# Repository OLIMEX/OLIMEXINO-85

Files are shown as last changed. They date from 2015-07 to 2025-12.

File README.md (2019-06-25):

This is the official repository for a number of OLIMEXINO-85 boards, manufactured by Olimex.

OLIMEXINO-85 boards are very tiny Arduino-like boards. They have functionality similar to Digistump's Digispark and Adafruit’s Trinket. The ATtiny85 microcontroller of each board comes preprogrammed with "Micronucleus" bootloater. This bootloader allows you to upload new software to the board via a personal computer and a USB cable. The boards work with the same Arduino distribution as Digispark.

In this repository you would find files suitable for the following boards:  

* OLIMEXINO-85-ASM: https://www.olimex.com/Products/Duino/AVR/OLIMEXINO-85-ASM/open-source-hardware
* OLIMEXINO-85-KIT: https://www.olimex.com/Products/Soldering-Kits/OLIMEXINO-85-KIT/open-source-hardware
* OLIMEXINO-85BC: https://www.olimex.com/Products/Duino/AVR/OLIMEXINO-85BC/open-source-hardware
* OLIMEXINO-85S: https://www.olimex.com/Products/Duino/AVR/OLIMEXINO-85S/open-source-hardware
* FOSDEM-85: https://www.olimex.com/Products/Soldering-Kits/FOSDEM-85/open-source-hardware

The SIMON-85 and SIMON-85-KIT boards have own repository available here: https://github.com/OLIMEX/SIMON-85

This repository contains a number of software files - firmware binaries, Arduino libraries, and ready-to-use examples. Note that the software files for the mentioned boards are the same for all boards in this repository. However, the hardware source files and pdfs for the above-mentioned boards are not the same.

##LICENSE
* Software License is GPL3
* Hardware License is Apache 2.0
* Documentation License is CC-BY-SA3.0 (https://creativecommons.org/licenses/by-sa/3.0/)

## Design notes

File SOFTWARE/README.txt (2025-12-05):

There are three sub-folders:

1. O85-examples
2. Libraries
3. Firmware

To be able to use the demos:

0. You need an Arduino IDE configured for DIGISPARK. You can configure Arduino IDE for ATtiny85 (OLIMEXINO-85-ASM, OLIMEXINO-85-KIT, FOSDEM-85, SIMON-85, SIMON-85-KIT, OLIMEXINO-85BC, OLIMEXINO-85S) following the advice here:

https://web.archive.org/web/20180831071913/http://digistump.com/wiki/digispark/tutorials/connecting

1. Copy the contents of the first folder of this archive "O85_examples" to xxx\arduino-x.x.x\examples\ folder.

2. Copy the contents of folder "libaries" to xxx\arduino-x.x.x\libraries. It is extremely important to paste only the contents there (do not create new folders in it else libraries would not be found).

3. You can now load the examples via Open->Examples or Open -> File in the Arduino IDE

Note that each example has a readme file in its folder detailing furhter how to use it and how it works.

Folder "Firmware" contains the bootloader that can be used to flash the board via any compatible AVR programmer in case of electrical failure or bootloader override.

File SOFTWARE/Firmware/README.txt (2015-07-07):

The firmware binaries are suitable for the following boards that feature ATtiny85: OLIMEXINO-85-KIT, OLIMEXINO-85-ASM, OLIMEXINO-85BC, OLIMEXINO-85S, FOSDEM-85, and FOSDEM-85-KIT

The OLIMEXINO-85 boards come programmed with the "Micronucleus" bootloader version 1.06. The offical "Micronucleus" repository can be found at the following address: https://github.com/micronucleus/micronucleus 

We used the Bluebie fork available here: https://github.com/Bluebie/micronucleus/tree/master/firmware/releases

NOTE: We are not supporting upgrading the firmware - the only suggested firmware is the bootloader version 1.06. It is provided in the respective folder.

1) Use AVR/Atmel Studio or AVRDude to upload respectivley the .elf or the .hex to the target ATtiny85.

The .elf file contains the proper fuses and configuration bits.

2) If you use AVRDude then you need to pass the fuse settings as command line:

lfuse:w:0xE1:m -U hfuse:w:0xDD:m -U efuse:w:0xFE:m

Usually the command to program the board via AVRDude looks like:

avrdude -c stk500v2 -P com26 -p t85 -U flash:w:Olimexino-85_ProductionTest_v_1_0_0.hex -U lfuse:w:0xE1:m -U hfuse:w:0xDD:m -U efuse:w:0xFE:m

,where

stk500v2 is the programmer's interface abriviation as per AVRdude's documentation
com26 is the serial interface in Windows; it would be something like ttyACM0 or similar
t85 is the abriviation of the name of the target microcontroller as per AVRdude's documentation
Olimexino-85_ProductionTest_v_2_0_0.hex is the name of our binary code

3) About the ATTINY85 Fuses
========================
FUSE - HEX value - Value description

Extended fuse - 0xFE – this value enables self programming and keeps the serial programming enabled

High fuse - 0xDD – this values sets PLL Clock; start-up time PWRDWN/RESET: 1K CK/14 CK + 64 ms

Low fuse - 0xE1 – this values sets brown-out detection at VCC=2.7 V

Refer to the user's manual of OLIMEXINO-85 for more information.

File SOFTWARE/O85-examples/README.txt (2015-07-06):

OLIMEXINO-85-ASM, OLIMEXINO-85-KIT, OLIMEXINO-85BC, OLIMEXINO-85S and FOSDEM-85 example package

1. Hardware and software prerequisites:

1x OLIMEXINO-85 board
1x cable to connect the board and your PC
1x properly installed Digispark Arduino IDE (please note that the examples won't work with stock Arduino IDE!)

Each example is archived as zip. Please extract it to a suitable folder to be able to load it in Arduino IDE. To prepare the Arduino IDE follow the guide available here:

http://digistump.com/wiki/digispark/tutorials/connecting

Some examples require additional hardware! Each example has explanation in the code comments!

2. The example list consists of:

85_ADCtoPWM.zip
85_BB_A4983.zip
85_BB_VNH3SP30.zip
85_BlinkingLed.zip
85_Button.zip
85_MOD_TC_MK2.zip
85_PWM.zip
85_Thermometer.zip

3. Remember:

- you need an Arduino IDE configured for DIGISPARK

- you need to click "Upload" button first, wait for the program to compile and THEN plug the board (this is because the bootloader implementation runs for the first few seconds after power up and then the user program is executed. If you plug the board before programming the bootloader won't be available and uploading will fail. Disconnect the board, click "Upload" again and then connect the board).

There are detailed instructions in the manual and the digispark's wiki pages.

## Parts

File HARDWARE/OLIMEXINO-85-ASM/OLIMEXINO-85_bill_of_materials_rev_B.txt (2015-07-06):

Partlist exported from D:/TortoiseSVN-Files/EagleProjects-LocalCopies/OLIMEXINO-85/Hardware/trunk/BRD/Olimexino-85_Rev_A.sch at 25/10/2013 8:02:23 

Qty Value                         Device          Parts                             
3   1.5k/0.125W                   R-EU_0204/5     R1, R2, R3                        
2   1N4148/DO35                   D1N4148-7.62MM  D1, D2                            
1   10uF/16V/105C(5x11mm,RM2)     CPOL-EUE2-5     C1                                
2   22R/0.125W                    R-EU_0204/5     R4, R5                            
1   100nF/2010                    C-EU025-025X050 C2                                
1   ATtiny85-20PU+(DIL-8)+(HR1x8) ATTINY85        U1                                
1   LED/3mm/Green                 LED3.0MM        PWR                               
1   LED/3mm/Red                   LED3.0MM        STAT                                                        
8   TESTPAD3                      TESTPAD3        #0, #1, #2, #3, #4, #RST, GND, VCC
1   TSR-1(T1101GP/6x3x4.3)        SW-TAKT3        RST                               
1   USB-B                         USB_SHIELD      USB

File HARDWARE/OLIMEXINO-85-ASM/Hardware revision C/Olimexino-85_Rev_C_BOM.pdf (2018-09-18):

Olimexino-85_Rev_C

Part | Value | Device | Package | Description
#0 | TESTPAD3 | TESTPAD3 | TEST_PAD40/70/SQUARE drill 40mils, diameter 70mils

#1 | TESTPAD3 | TESTPAD3 | TEST_PAD40/70/SQUARE drill 40mils, diameter 70mils

#2 | TESTPAD3 | TESTPAD3 | TEST_PAD40/70/SQUARE drill 40mils, diameter 70mils

#3 | TESTPAD3 | TESTPAD3 | TEST_PAD40/70/SQUARE drill 40mils, diameter 70mils

#4 | TESTPAD3 | TESTPAD3 | TEST_PAD40/70/SQUARE drill 40mils, diameter 70mils

#RST | TESTPAD3 | TESTPAD3 | TEST_PAD40/70/SQUARE drill 40mils, diameter 70mils

C1 | 10uF/16V/105C(5x11mm,RM2) | CPOL-EUE2-5 | E2-5 | POLARIZED CAPACITOR, European symbol
C2 | 100nF/2010 | C-EU025-025X050 | C025-025X050 | CAPACITOR, European symbol
D1 | 1N4148/DO35 | D1N4148-7.62MM | DO35-10 | DIODES
D2 | 1N4148/DO35 | D1N4148-7.62MM | DO35-10 | DIODES
GND | TESTPAD3 | TESTPAD3 | TEST_PAD40/70/SQUARE drill 40mils, diameter 70mils
PWR | LED/3mm/Green | LED3.0MM | LED-3.0MM
R1 | 1.5k/0.125W | R-EU_0204/5 | 0204/5 | RESISTOR, European symbol
R2 | 1.5k/0.125W | R-EU_0204/5 | 0204/5 | RESISTOR, European symbol
R3 | 1.5k/0.125W | R-EU_0204/5 | 0204/5 | RESISTOR, European symbol
R4 | 22R/0.125W | R-EU_0204/5 | 0204/5 | RESISTOR, European symbol
R5 | 22R/0.125W | R-EU_0204/5 | 0204/5 | RESISTOR, European symbol
R6 | NA | R-EU_R0603_5MIL_DWS R0603_5MIL_DWS | RESISTOR, European symbol
R7 | NA | R-EU_R0603_5MIL_DWS R0603_5MIL_DWS | RESISTOR, European symbol
R8 | NA | R-EU_R0603_5MIL_DWS R0603_5MIL_DWS | RESISTOR, European symbol
RST | TSR-1(T1101GP/6x3x4.3) | SW-TAKT3 | SW-TAKT6X3.5
RST_E Open | SJSJ_SMALLER | SJ_1_SMALLER | SMD solder JUMPER
STAT | LED/3mm/Red | LED3.0MM | LED-3.0MM
U1 | ATtiny85-20PU+(DIL-8)+(HR1x8) ATTINY85 | DIP8
USB | USB-B | USB_SHIELD | USB_NEAR_BLACK
VCC | TESTPAD3 | TESTPAD3 | TEST_PAD40/70/SQUARE drill 40mils, diameter 70mils
Z1 | NA(BZV55C3V6/SOD80C) | ZDIOD-SMD | MINI-MELF
Z2 | NA(BZV55C3V6/SOD80C) | ZDIOD-SMD | MINI-MELF

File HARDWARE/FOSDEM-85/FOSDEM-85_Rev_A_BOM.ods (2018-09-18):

Part | Value | Device | Package | Description
#0 | TESTPAD3 | TESTPAD3 | TEST_PAD40/70/SQUARE | drill 40mils, diameter 70mils
#1 | TESTPAD3 | TESTPAD3 | TEST_PAD40/70/SQUARE | drill 40mils, diameter 70mils
#2 | TESTPAD3 | TESTPAD3 | TEST_PAD40/70/SQUARE | drill 40mils, diameter 70mils
#3 | TESTPAD3 | TESTPAD3 | TEST_PAD40/70/SQUARE | drill 40mils, diameter 70mils
#4 | TESTPAD3 | TESTPAD3 | TEST_PAD40/70/SQUARE | drill 40mils, diameter 70mils
#RST | TESTPAD3 | TESTPAD3 | TEST_PAD40/70/SQUARE | drill 40mils, diameter 70mils
BAT-3.7V | DW02S | CON2DW02S | DW02S
C1 | 10uF/16V/105C(5x11mm,RM2) | CPOL-EUE2-5 | E2-5 | POLARIZED CAPACITOR, European symbol
C2 | 100nF/2010 | C-EU025-025X050 | C025-025X050 | CAPACITOR, European symbol
D1 | 1N4148/DO35 | DDO35 | DO35-200MILS | DIODES
D2 | 1N4148/DO35 | DDO35 | DO35-200MILS | DIODES
D3 | 1N4148/DO35 | DDO35 | DO35-200MILS | DIODES
GND | TESTPAD3 | TESTPAD3 | TEST_PAD40/70/SQUARE | drill 40mils, diameter 70mils
PWR | LED/3mm/Green | LED3.0MM | LED-3.0MM
R1 | 10k/0.125W | R-EU_0204/5 | 0204/5 | RESISTOR, European symbol
R2 | 1.5k/0.125W | R-EU_0204/5 | 0204/5 | RESISTOR, European symbol
R3 | 1.5k/0.125W | R-EU_0204/5 | 0204/5 | RESISTOR, European symbol
R4 | 22R/0.125W | R-EU_0204/5 | 0204/5 | RESISTOR, European symbol
R5 | 22R/0.125W | R-EU_0204/5 | 0204/5 | RESISTOR, European symbol
R6 | 10k/0.125W | R-EU_0204/5 | 0204/5 | RESISTOR, European symbol
STAT | LED/3mm/Red | LED3.0MM | LED-3.0MM
U1 | ATtiny85-20PU+(DIL-8) | ATTINY85-20PU | DIP8 | Atmel 8-bit AVR 2/4/8KB In-System Programmable Flash
USB | USB-B | USB_SHIELD | USB_NEAR_BLACK
VCC | TESTPAD3 | TESTPAD3 | TEST_PAD40/70/SQUARE | drill 40mils, diameter 70mils

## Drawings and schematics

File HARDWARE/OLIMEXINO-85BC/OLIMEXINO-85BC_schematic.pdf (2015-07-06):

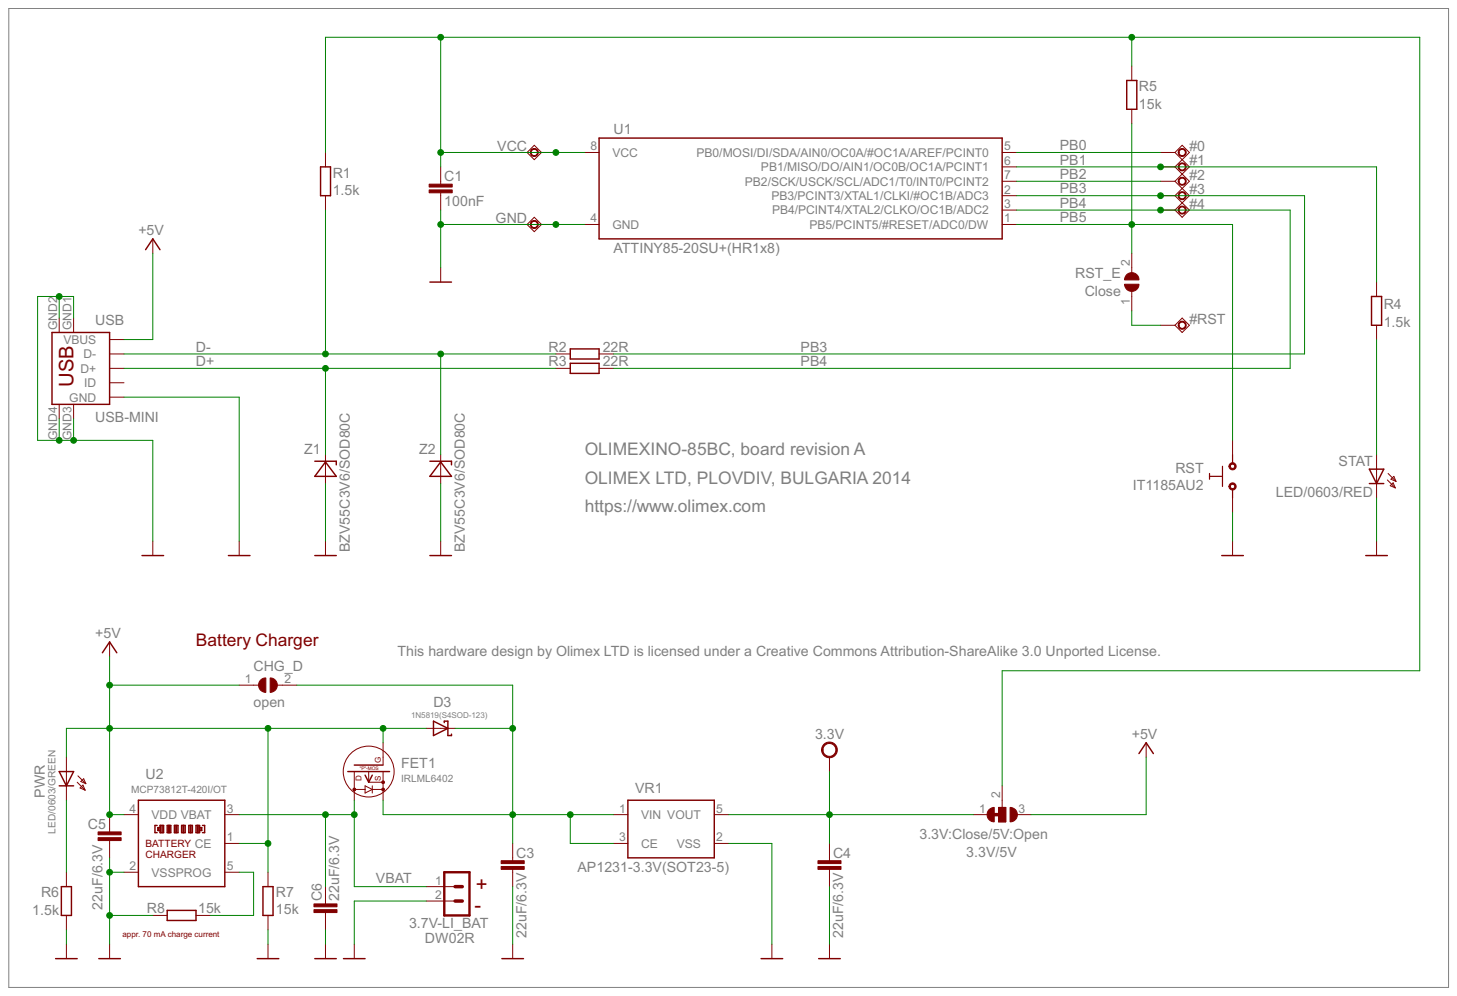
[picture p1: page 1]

6 PB0/MOSI/DI/SDA/AIN0/OC0A/#OC1A/AREF/PCINT0

PB4 | #4
PB5

OLIMEXINO-85BC, board revision A
OLIMEX LTD, PLOVDIV, BULGARIA 2014
https://www.olimex.com

This hardware design by Olimex LTD is licensed under a Creative Commons Attribution-ShareAlike 3.0 Unported License.

appr. 70 mA charge current

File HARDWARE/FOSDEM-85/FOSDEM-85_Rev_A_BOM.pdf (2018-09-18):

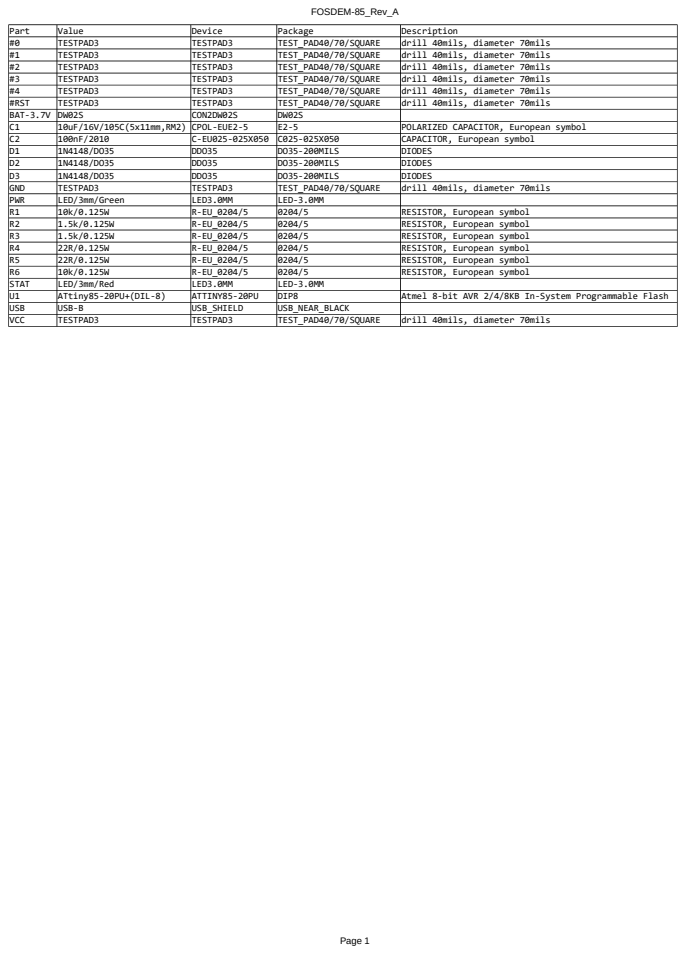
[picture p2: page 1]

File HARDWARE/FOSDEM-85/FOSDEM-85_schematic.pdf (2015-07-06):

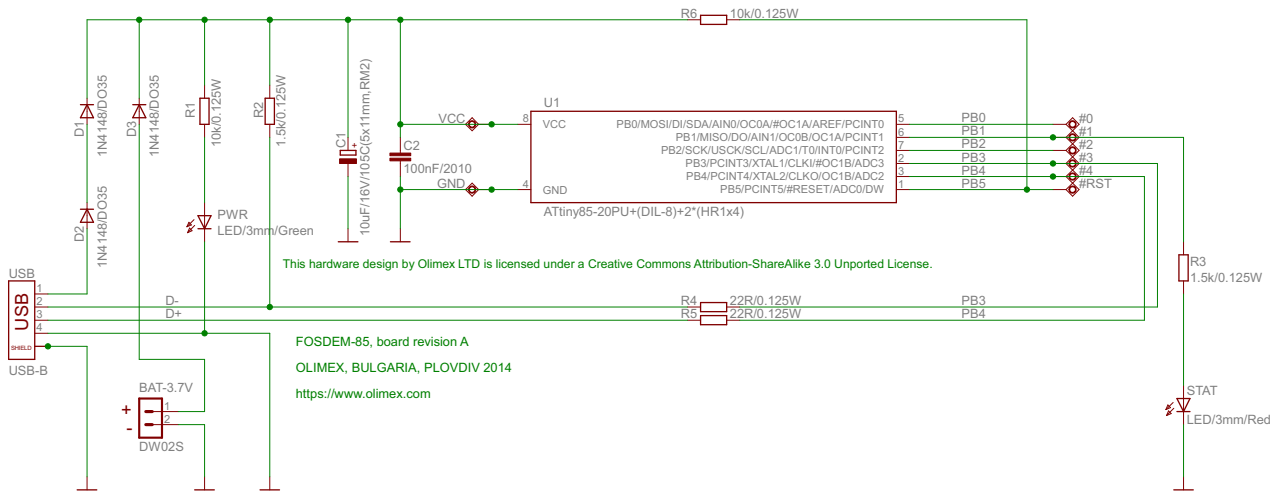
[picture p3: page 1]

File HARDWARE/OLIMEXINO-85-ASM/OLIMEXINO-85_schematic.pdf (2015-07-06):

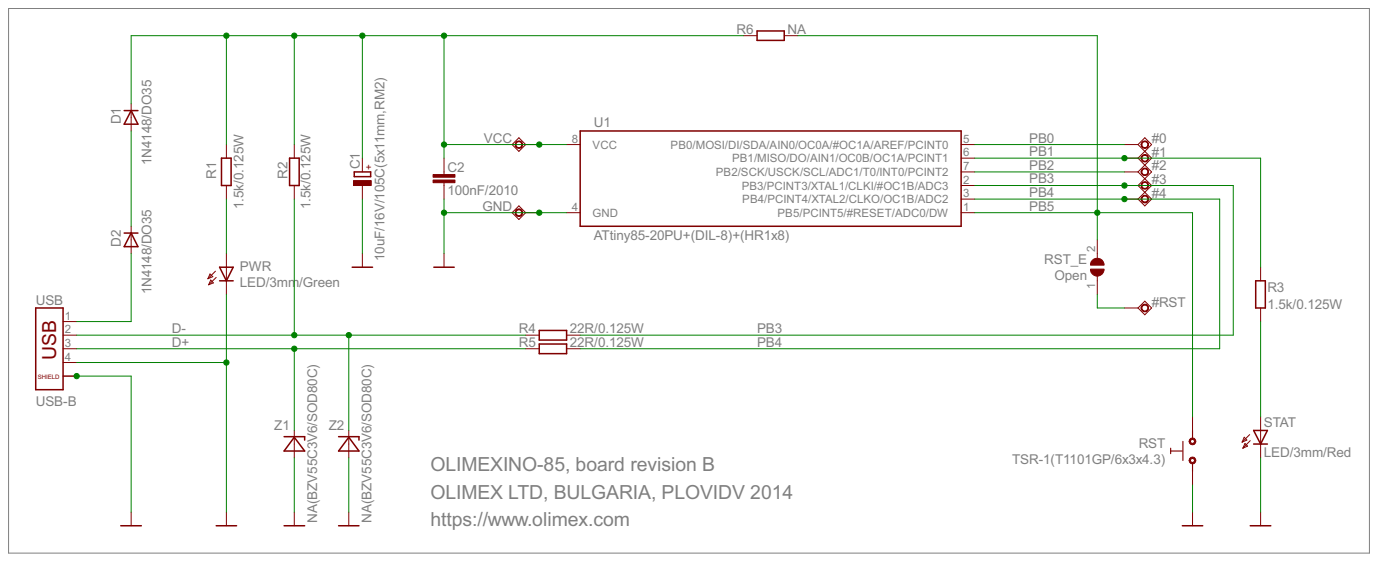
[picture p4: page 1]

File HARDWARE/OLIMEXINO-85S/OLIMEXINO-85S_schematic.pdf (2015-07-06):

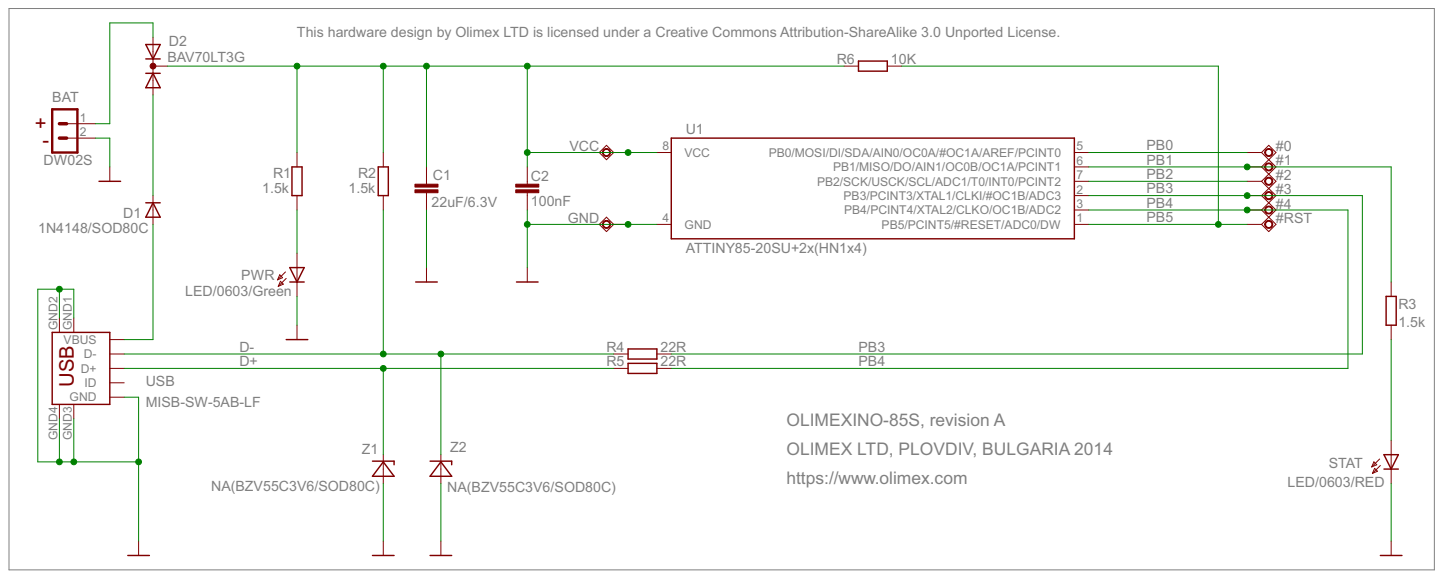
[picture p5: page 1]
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

6 PB0/MOSI/DI/SDA/AIN0/OC0A/#OC1A/AREF/PCINT0

OLIMEXINO-85S, revision A
OLIMEX LTD, PLOVDIV, BULGARIA 2014
https://www.olimex.com

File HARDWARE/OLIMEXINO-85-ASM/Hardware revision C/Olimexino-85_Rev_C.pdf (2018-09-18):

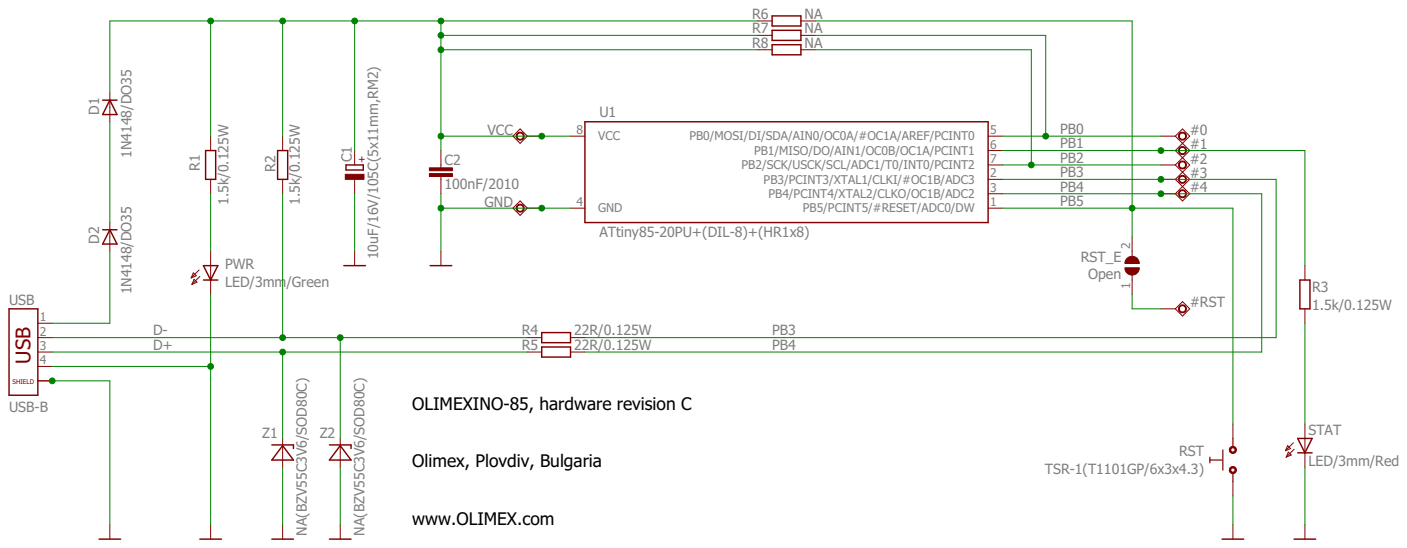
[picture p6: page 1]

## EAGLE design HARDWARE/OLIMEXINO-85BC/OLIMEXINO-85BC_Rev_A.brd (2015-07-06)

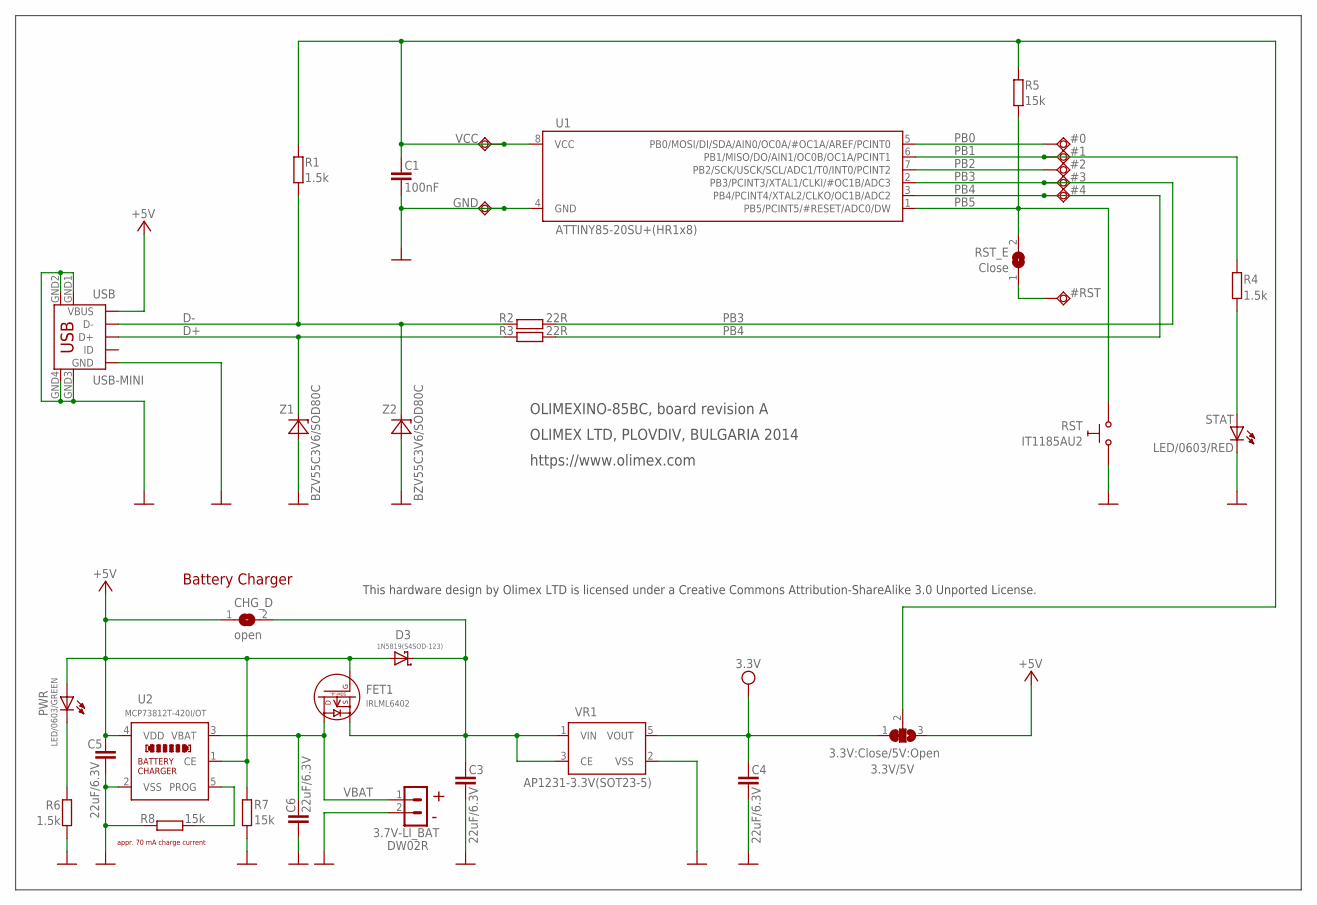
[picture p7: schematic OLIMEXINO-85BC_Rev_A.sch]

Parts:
3.3V/5V: 3.3V:Close/5V:Open; SJ_2_SMALL
3.7V-LI_BAT: DW02R
#0, #1, #2, #3, #4: TESTPAD3; TEST_PAD40/70/SQUARE
#RST: TESTPAD3; TEST_PAD40/70/SQUARE
C1: 100nF; C0603_DWS
C3, C4, C5, C6: 22uF/6.3V; C0603_DWS
CHG_D: open; SJ_1_SMALLER
D3: 1N5819(S4SOD-123); SOD-123
FET1: IRLML6402; SOT23
GND: TESTPAD3; TEST_PAD40/70/SQUARE
PWR: LED/0603/GREEN; LED-0603
R1, R4, R6: 1.5k; R0603_5MIL_DWS
R2, R3: 22R; R0603_5MIL_DWS
R5, R7, R8: 15k; R0603_5MIL_DWS
RST: IT1185AU2
RST_E: Close; SJ_1_SMALLER
STAT: LED/0603/RED; LED-0603
U1: ATTINY85-20SU+(HR1x8); SO-8
U2: MCP73812T-420I/OT; SOT-23-5
USB: USB-MINI; USB_MINI_9PIN
VCC: TESTPAD3; TEST_PAD40/70/SQUARE
VR1: AP1231-3.3V(SOT23-5); SOT-23-5
Z1, Z2: BZV55C3V6/SOD80C; MINI-MELF

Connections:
+5V: 3.3V/5V.3, C5.1, CHG_D.1, D3.A, FET1.1 (G), PWR.A, R7.1, U2.1 (CE), U2.4 (VDD), USB.VBUS
D+: R3.1, USB.D+, Z1.1 (C)
D-: R1.1, R2.1, USB.D-, Z2.1 (C)
GND: 3.7V-LI_BAT.2, C1.2, C3.2, C4.2, C5.2, C6.2, GND.P$1, R6.2, R7.2, R8.1, RST.2 (1), STAT.C, U1.4 (GND), U2.2 (VSS), USB.GND, USB.GND1, USB.GND2, USB.GND3, USB.GND4, VR1.2 (VSS), Z1.2 (A), Z2.2 (A)
MCU_VCC: 3.3V/5V.2, C1.1, R1.2, R5.2, U1.8 (VCC), VCC.P$1
unnamed: #RST.P$1, RST_E.1
unnamed: R4.1, STAT.A
unnamed: PWR.C, R6.1
unnamed: R8.2, U2.5 (PROG)
PB0: #0.P$1, U1.5 (PB0/MOSI/DI/SDA/AIN0/OC0A/#OC1A/AREF/PC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)
PB1: #1.P$1, R4.2, U1.6 (PB1/MISO/DO/AIN1/OC0B/OC1A/PCINT1)
PB2: #2.P$1, U1.7 (PB2/SCK/USCK/SCL/ADC1/T0/INT0/PCINT2)
PB3: #3.P$1, R2.2, U1.2 (PB3/PCINT3/XTAL1/CLKI/#OC1B/ADC3)
PB4: #4.P$1, R3.2, U1.3 (PB4/PCINT4/XTAL2/CLKO/OC1B/ADC2)
PB5: R5.1, RST.1 (0), RST_E.2, U1.1 (PB5/PCINT5/#RESET/ADC0/DW)
VBAT: 3.7V-LI_BAT.1, C6.1, FET1.3 (D), U2.3 (VBAT)
VCC: 3.3V/5V.1, C4.1, VR1.5 (VOUT)
VIN: C3.1, CHG_D.2, D3.C, FET1.2 (S), VR1.1 (VIN), VR1.3 (CE)

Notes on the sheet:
Battery Charger
appr. 70 mA charge current
OLIMEXINO-85BC, board revision A
OLIMEX LTD, PLOVDIV, BULGARIA 2014
https://www.olimex.com
This hardware design by Olimex LTD is licensed under a Creative Commons Attribution-ShareAlike 3.0 Unported License.

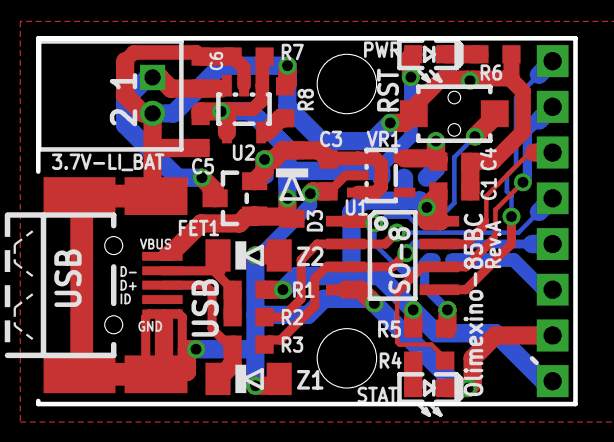
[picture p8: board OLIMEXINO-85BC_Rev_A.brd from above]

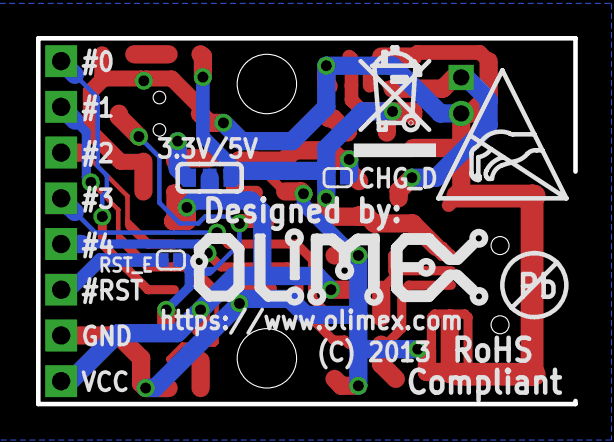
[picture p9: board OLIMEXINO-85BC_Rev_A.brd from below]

Board: 2 copper layers, 29.8 x 20.3 mm, 40 parts (7 on the bottom side), 18 nets.

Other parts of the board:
U$1: RECYCLE_BIN1/8
U$2: OLIMEX1_V
U$3: ESD_SYMBOL
U$4: PB_SMALL

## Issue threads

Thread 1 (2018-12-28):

Installing olimex package library in Arduino

rvegele, 2018-12-28:
The following link seems to be dead:
https://raw.githubusercontent.com/OLIMEX/Arduino_configurations/master/AVR/package_olimex _avr_index.json

Getting an error in arduino ide

newtob, 2021-08-04:
I concur, any ideas where it might be re-listed?

hehopmajieh, 2021-08-04:
Link is ok, try with :
https://raw.githubusercontent.com/OLIMEX/Arduino_configurations/master/AVR/package_olimex_avr_index.json

На ср, 4.08.2021 г. в 10:38 ч. Ben ***@***.***> написа:

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

newtob, 2021-08-04:
You'r a superstar, it works!!

Many thanks,
B
_______
Ben

On Wed, 4 Aug 2021 at 09:21, Dimitar Gamishev ***@***.***>
wrote:

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

Closed 2021-08-17.

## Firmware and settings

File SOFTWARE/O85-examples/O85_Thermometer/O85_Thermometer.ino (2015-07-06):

/**********************************************************************************/
/*    Demo Program for:          						  */
/*	  Board: Olimexino-85                 					  */
/*    Manufacture: OLIMEX                                                   	  */
/*	  COPYRIGHT (C) 2014							  */
/*    Designed by:  Penko T. Bozhkov                                              */
/*    Revision       :  1.0.0 (initial)                                           */
/*    Date           :  31.01.2014                                                */
/*   Built with Arduino C/C++ Compiler, version: 1.0.4                            */
/**********************************************************************************/
// Very important!!!!! Change the I2C buffer size from 16 to 30!!!!!!!!!!!!!!!!!!!!
// Goto Digispark-Arduino-1.0.4\libraries\TinyWireM_Digispark\TinyWire.h and chage:
// #define USI_BUF_SIZE    30              // bytes in message buffer
// In other case, the demo will not work correctly
/*
  Action:
  =======
  Reads the temperature via MOD-TC-MK2-31855 and displays the value to MOD-LCD-1x9.
  https://www.olimex.com/Products/Modules/Sensors/MOD-TC-MK2-31855/open-source-hardware
  https://www.olimex.com/Products/Components/Misc/TC-K-TYPE/
  https://www.olimex.com/Products/Modules/LCD/MOD-LCD-1x9/open-source-hardware
  To connect all boards together we have used one UEXTx5 board as well: 
  https://www.olimex.com/Products/Modules/Interface/UEXTx5/open-source-hardware
  
  Notes: 
    1. Beware VCC not to exceed (3.6~3.8)V!!!!!
    2. Ensure MOD-TC-MK2-31855 I2C pull-ups are not disconnected!
 
  Simple Schematic:
  =================                                                          |----------------------|
  |---------------------------|       |--------------------------|           |   MOD-TC-MK2-31855   |
  |                    |  #0  |-------| UEXT1<6>        UEXT3<6> |-----------| UEXT<6>            T+|------\  +
  |                    |  #1  |       |                 UEXT3<5> |-----------| UEXT<5>              |       o Thermocouple(TC-K-TYPE)
  |                    |  #2  |-------| UEXT1<5>        UEXT3<2> |-----------| UEXT<2>            T-|------/  -
  |    OLIMEXINO-85    |  #3  |       |            U    UEXT3<1> |-----------| UEXT<1>              |
  |                    |  #4  |       |            E             |           |----------------------|
  |                    | #RST |       |            X             |                                
  |                    | GND  |-------| UEXT1<2>   T             |           |------------------| D |
  |                    | VCC  |-------| UEXT1<1>   x    UEXT5<6> |-----------| UEXT<6>          | I |
  |---------------------------|       |            5    UEXT5<5> |-----------| UEXT<5>          | S |
                                      |                 UEXT5<2> |-----------| UEXT<2>          | P |
                                      |                 UEXT5<1> |-----------| UEXT<1>          | L |
                                      |--------------------------|           |    MOD-LCD-1x9   | A |
                                                                             |------------------| Y |

  To upload to your Olimexino-85:
  1) Select the proper board from the Tools->Board Menu->Digispark 8mhz - NO USB(Tiny Core)
  2) Select Digispark from the Tools->Programmer
  3) Press the Upload button
  4) When you see the message: "Plug in device now... (will timeout in 60 seconds)", Plug in the Olimexino-85
*/
#include <USI_TWI_Master.h>
#include <TinyWireM.h>      // By default: SCL -> PB2(#2), SDA -> PB0(#0)
//#include <avr/pgmspace.h>
#include <LCD1x9.h>
#include <inttypes.h>

#define MOD_TC_MK2_ADDR   0x23 
#define GET_TEMP	  0x21

#define LED1_PIN         1              // ATtiny85 Pin 6, PB1(#1)
#define LED2_PIN         4              // ATtiny85 Pin 3, PB4(#4)

char TempValue[9] = {'T','e','m','p',' ',' ',' ','&','C'};
uint16_t count = 1;
uint16_t tempC = 0;                     // holds temp in C
//uint16_t tempF = 0;                     // holds temp in F


/****************************************************/
/*  Function name: TC_MK2_temperatureRead           */
/*  Parameters                                      */
/*    Input   :  No                                 */
/*    Output  :  temp                               */
/*    Action: Returns the MAX31855KASA+'s temp data.*/
/****************************************************/
uint32_t TC_MK2_temperatureRead(){
  uint32_t temp;
  uint8_t data[4];
  uint8_t i = 0;
  
  TinyWireM.beginTransmission(MOD_TC_MK2_ADDR);
  TinyWireM.send(GET_TEMP);
  TinyWireM.endTransmission();
  TinyWireM.requestFrom(MOD_TC_MK2_ADDR,4);
  
  while(TinyWireM.available() > 0)
    data[i++] = TinyWireM.receive();
  
  temp = data[3];
  temp <<= 8;
  temp |= data[2];
  temp <<= 8;
  temp |= data[1];
  temp <<= 8;
  temp |= data[0];
  
  return temp;
}


/****************************************************/
/*  Function name: Blink                            */
/*  Parameters                                      */
/*    Input   :  led, times                         */
/*    Output  :  No                                 */
/*    Action: Blinks the selected led.              */
/****************************************************/
void Blink(byte led, byte times){
  for (byte i=0; i<(times<<2); i++){
    if(digitalRead(led)==LOW){
      digitalWrite(led,HIGH);
      delay (500);
    }
    else{
      digitalWrite(led,LOW);
      delay (100);
    }
  }
}


/****************************************************/
/*  Function name: setup                            */
/*  Parameters                                      */
/*    Input   :  No	                            */
/*    Output  :  No                                 */
/*    Action: Initializes all peripherals           */
/****************************************************/
void setup() {
  
  pinMode(LED1_PIN,OUTPUT);
  pinMode(LED2_PIN,OUTPUT);
  Blink(LED1_PIN,2);         // show it's alive
  
  TinyWireM.begin();         // I2C init
  lcd.init();
  
  digitalWrite(LED1_PIN,HIGH);
  digitalWrite(LED2_PIN,LOW);
  
  delay (100);
  lcd.write("*Welcome*");
  delay (1000);
}


/****************************************************/
/*  Function name: loop                             */
/*  Parameters                                      */
/*    Input   :  No	                            */
/*    Output  :  No                                 */
/*    Action: Reads and displays the temperature.   */
/****************************************************/ 
void loop() {
  float ex_f;
  unsigned char ex_s=0;
  
  uint32_t c = TC_MK2_temperatureRead();
  
  // Check for fault
  if(c & 0x00010000){
    // Fault detected
  }
  else{
    ex_s = !!(c & 0x80000000);  // Take the Sign bit value: 0 positive,  1 negative temperature
    // Convert external temperature
    uint16_t ext = (c >> 16 );                // Get the thermocouple temperature data(external temperature) 
    ext &= (0x7FFF);                          // Mask the Sign bit
    ext >>= 2;                                // Ignore the D17(reserved) and D16(Fault) bits
    ex_f = (ext >> 2) + (ext & 0x03) * 0.25;  // Calculate the temperature when positive
    if(ex_s)
      ex_f = 2048 - ex_f;                     // Calculate the temperature when negative
      
    tempC = (uint16_t)ex_f;                   // get the temperature
    //tempF = tempC * 9 / 5 + 32;             // convert to Fahrenheit
     
  }
  
  //Write LCD String
  if(tempC/100){  
    TempValue[4] = (uint8_t)((tempC/100)+ '0');
    if((tempC%100)<10){
      TempValue[5] = (uint8_t)('0');
      TempValue[6] = (uint8_t)((tempC%100)+ '0');
    }
    else{
      TempValue[5] = (uint8_t)(((tempC%100)/10)+ '0');
      TempValue[6] = (uint8_t)(((tempC%100)%10)+ '0');
    }  
  }
  else{ 
    if(ex_s){
     //The measured temperature is negative
     if(tempC/10){  TempValue[4] = (uint8_t)('-');  }
     else{          TempValue[4] = (uint8_t)(' ');  }
    }
    else{  TempValue[4] = (uint8_t)(' ');  }
    // Check the 10's
    if(tempC/10){
      TempValue[5] = (uint8_t)((tempC/10)+ '0');
      TempValue[6] = (uint8_t)((tempC%10)+ '0');
    }
    else{
      if(ex_s){
        //The measured temperature is negative
        if(tempC){  TempValue[5] = (uint8_t)('-');  }
        else{       TempValue[5] = (uint8_t)(' ');  }
      }
      else{         TempValue[5] = (uint8_t)(' ');  }
      TempValue[6] = (uint8_t)((tempC%10)+ '0');  
    }
  }
  
  // Display the string
  lcd.write(TempValue);
  
 ///* 
  count++;
  if(count==1000){
    count = 0;
    Blink(LED1_PIN,1);
  }
//*/
  
}
 
 
 

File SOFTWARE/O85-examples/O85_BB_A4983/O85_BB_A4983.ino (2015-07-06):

/**********************************************************************************/
/*    Demo Program for:          						  */
/*	  Board: Olimexino-85                    				  */
/*    Manufacture: OLIMEX                                                   	  */
/*	  COPYRIGHT (C) 2013							  */
/*    Designed by: Engineer Penko T. Bozhkov                                      */
/*    Revision       :  1.0.0 (initial)                                           */
/*    Date           :  31.10.2013                                                */
/*   Built with Arduino C/C++ Compiler, version: 1.0.4                            */
/**********************************************************************************/
/*
  Action:
  =======
  This simple program is designed by using Olimexino-85 board and BB-A4983 connected to it.
  A4983 is a complete microstepping motor driver with built-in translator for easy operation. 
  A 12VDC 2-phase step engine was connected to the BB-A4983 board's connectors OUT1 ans OUT2.
  When the program is running, the motor makes one 360 degree clockwise rotation(if connected correctly) and stops.
  Then one 360 degree counterclockwise rotation and stops. Afterwards the described cycle is constantly repeated.
  The step engine must be connected as follows: Coil<1>*(Begin) to OUT1A;  Coil<1>(End) to OUT1B
                                                Coil<2>*(Begin) to OUT2A;  Coil<2>(End) to OUT2B

  Simple Schematic:
  =================
  |---------------------------|              |----------------------------------------|
  |                    |  #0  |------------->| CTRL<5>,  SLEEP     B         OUT2<B>  |---------> Step engine Coil<2>(End)
  |                    |  #1  |------------->| CTRL<6>,  STEP      B         OUT2<A>  |---------> Step engine Coil<2>*(Begin)
  |                    |  #2  |------------->| CTRL<7>,  DIR       |                  |
  |    OLIMEXINO-85    |  #3  |      |------>| CTRL<2>,  MS1       A         OUT1<A>  |---------> Step engine Coil<1>*(Begin)
  |                    |  #4  |------o------>| CTRL<3>,  MS2   BB-A4983      OUT1<B>  |---------> Step engine Coil<1>(End)
  |                    | #RST |      |------>| CTRL<4>,  MS3       9                  |
  |                    | GND  |------------->| CTRL<10>, GND       8     PWR<2>, GND  |<--------- GND   from External power supply
  |                    | VCC  |------------->| CTRL<1>,  VDD       3     PWR<1>, VIN  |<--------- 12VDC from External power supply
  |---------------------------|              |----------------------------------------|

  To upload to your Olimexino-85:
  1) Select the proper board from the Tools->Board Menu->Digispark 8mhz - NO USB(Tiny Core)
  2) Select Digispark from the Tools->Programmer
  3) Press the Upload button
  4) When you see the message: "Plug in device now... (will timeout in 60 seconds)", Plug in the Olimexino-85

*/


// Select pin numbers:
#define    Sleep       0        // Mode of operation: Active/Sleep
#define    STEP        1        // A low-to-high transition on the STEP input sequences the translator and advances the motor one increment.
#define    DIR         2        // Direction of rotation
#define    MSx         4        // Microstep Select

#define    Threshold   640


// Variables will change:
int StepState = LOW;            // StepState used to set the STEP
long previousMillis = 0;        // will store last time STEP was updated
int counter = 0;
volatile int index = 0;
long interval = 0.1;            // interval at which to make a STEP

void setup() {
  // set the digital pin as output:
  pinMode(STEP, OUTPUT); 
  pinMode(DIR, OUTPUT);
  pinMode(Sleep, OUTPUT);
  pinMode(MSx, OUTPUT);       // MS1..3 Inputs Step control
  
  //Set the state
  digitalWrite(STEP, LOW);      
  digitalWrite(DIR, LOW);     // direction will be clockwise
  //digitalWrite(DIR, HIGH);    // direction will be counterclockwise
  //digitalWrite(Sleep, LOW);     // A4983 into Sleep mode.
  digitalWrite(Sleep, HIGH);    // A4983 into normal operation
  digitalWrite(MSx, HIGH);  // Sixteenth Step  
  //digitalWrite(MSx, LOW);     // Full Step 
}

void loop()
{
  unsigned long currentMillis = millis();
 
  if(currentMillis - previousMillis > interval) {
    previousMillis = currentMillis;   

    // if the STEP is off turn it on and vice-versa:
    if (StepState == LOW)
      StepState = HIGH;
    else
      StepState = LOW;

    // set the STEP with the StepState of the variable:
    digitalWrite(STEP, StepState);
    
    counter++;
    
    if(counter >= Threshold){
      counter = 0;
      index++;   
      if(index == 1){
        digitalWrite(Sleep, LOW);     // A4983 into Sleep mode.
      } 
      else if(index == 2){
        digitalWrite(DIR, HIGH);      // direction will be counterclockwise
        digitalWrite(Sleep, HIGH);    // A4983 into normal operation
        digitalWrite(STEP, LOW);
      }
      else if(index == 3){
        digitalWrite(Sleep, LOW);     // A4983 into Sleep mode.
      }
      else{
        index = 0;
        digitalWrite(STEP, LOW);
        digitalWrite(DIR, LOW);       // direction will be clockwise
        digitalWrite(Sleep, HIGH);    // A4983 into normal operation
      }
    }
    
  }
}

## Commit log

2015-07-06 85 boards update
    [FOSDEM-85_Rev_A.brd, FOSDEM-85_Rev_A.sch, OLIMEXINO-85BC_Rev_A.brd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]
2018-09-18 Updated
    BOMs and gerbers
    [FOSDEM-85_Rev_A.csv, FOSDEM-85_Rev_A_BOM.ods, Olimexino-85_Rev_C.brd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]
2025-12-04 Fix link to Arduino IDE configuration for DIGISPARK
    Updated the link for configuring Arduino IDE for DIGISPARK to an archived version.
